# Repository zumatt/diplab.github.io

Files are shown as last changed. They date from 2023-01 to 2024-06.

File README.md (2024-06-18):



# DiPLab - Digital Petri Laboratory


DiPLab is a project that is part of [MAKEAWARE!](https://spearhead-amr.github.io/makeaware/) , which aims to raise awareness about the issue of [Antibiotic Resistance](https://www.who.int/news-room/fact-sheets/detail/antibiotic-resistance).

By digitizing the [antibiogram test](https://en.wikipedia.org/wiki/Antibiotic_sensitivity_testing), it is now possible to experience it outside of microbiology laboratories. This workshop provides an exciting opportunity for participants to deepen their understanding of antibiotics and antibiotic resistance. Additionally, participants will have the chance to engage in practical activities and learn about the test in a hands-on setting. This comprehensive workshop aims to help participants gain a deeper appreciation for the significance of antibiotics and their impact on daily life. By attending this workshop, participants will be able to broaden their knowledge of antibiotics and antibiotic resistance and explore the role of these life-saving drugs in modern medicine.

This repository contains the stable version of the DiPLab. In order to create your own digital petri you can download the source code and the 3D files from the releases.

The project has started as a personal thesis project developed during the [SUPSI Master of Arts in Interaction Design](https://maind.supsi.ch).



## Bugs & Issues

If you want to report an issue, you can submit it to the [issue tracker](https://github.com/zumatt/diplab/issues) of this repository.

## Repository info

Inside the main branch you will find the stable version of DiPLab. However, if you want to create your own digital petri is suggested to download the [latest release](https://github.com/zumatt/diplab/releases) and follow the tutorial that you can find here below.
The main branch is divided into hardware and software. In the hardware you will find the 3D files used to create the external case of the DiPLab. In the software folder you will find anything connected to the digital development of the digital petri, here inside you can find the Arduino source code and the application source code.

## Hardware

The project is based on the board [Soldered Inkplate 6PLUS](https://soldered.com/product/soldered-inkplate-6plus-with-enclosure-e-paper-display-with-touchscreen-usb-only/) with an additional custom board to add the accellerometer sensor into the project.
If you want to replicate the experience, you can buy the mother board [here](https://soldered.com/product/soldered-inkplate-6plus-with-enclosure-e-paper-display-with-touchscreen-usb-only/) and print the custom PCB with the files contained into the folder hardware>accellerometer PCB

## Installation tutorial

In order to create your own digital petri you need to be aware on how to use a 3D Printer and have basic knowledge of Arduino and coding.
The tutorial will be developed soon...

## License

The code contained in this repository and the executable distributions are licensed under the terms of the [MIT License](https://mit-license.org/). The project is released under the terms of the [CC BY SA](https://creativecommons.org/licenses/by-sa/2.0/) license.

[][cc-by-sa]

[cc-by-sa]: http://creativecommons.org/licenses/by-sa/4.0/
[cc-by-sa-image]: https://i.creativecommons.org/l/by-sa/4.0/88x31.png
[cc-by-sa-shield]: https://img.shields.io/badge/License-CC%20BY%20SA%204.0-lightgrey.svg

## Acknowledgments




MAKEAWARE! is part of [Spearhead Project](https://spearhead-project.ch/). [Innosuisse Flagship 2022-24](https://www.innosuisse.ch/inno/en/home/promotion-of-national-projects/flagship-initiative.html).

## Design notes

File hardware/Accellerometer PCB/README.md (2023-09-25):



# DiPLab - Digital Petri Laboratory

DiPLab is a project that is part of [MAKEAWARE!](https://spearhead-amr.github.io/makeaware/) , which aims to raise awareness about the issue of [Antibiotic Resistance](https://www.who.int/news-room/fact-sheets/detail/antibiotic-resistance).

## Accellerometer PCB

This part of the repository contains the personalised PCB created in order to add the accellerometer to the [Inkplate 6 PLUS](https://github.com/SolderedElectronics/Soldered-Inkplate-6PLUS-hardware-design).



The board is based on the [LIS3DH accellerometer](https://www.st.com/resource/en/datasheet/lis3dh.pdf) component and the [easyC connector](https://soldered.com/easyC/) from Soldered Electronics.
Is it possible to use the accellerometer for any purpose including other boards using the 4 through-hole pins.
The shield is designed in collaboration with [Marco Lurati](https://github.com/marclura).

## Bugs & Issues

If you want to report an issue, you can submit it to the [issue tracker](https://github.com/zumatt/diplab/issues) of this repository.

## Repository info

Inside the main branch you will find the stable version of DiPLab. However, if you want to create your own digital petri is suggested to download the [latest release](https://github.com/zumatt/diplab/releases) and follow the tutorial that you can find here below.
The main branch is divided into hardware and software. In the hardware you will find the 3D files used to create the external case of the DiPLab. In the software folder you will find anything connected to the digital development of the digital petri, here inside you can find the Arduino source code and the application source code.

## License

The code contained in this repository and the executable distributions are licensed under the terms of the [MIT License](https://mit-license.org/). The project is released under the terms of the [CC BY SA](https://creativecommons.org/licenses/by-sa/2.0/) license.

[][cc-by-sa]

[cc-by-sa]: http://creativecommons.org/licenses/by-sa/4.0/
[cc-by-sa-image]: https://i.creativecommons.org/l/by-sa/4.0/88x31.png
[cc-by-sa-shield]: https://img.shields.io/badge/License-CC%20BY%20SA%204.0-lightgrey.svg

## Acknowledgments




MAKEAWARE! is part of [Spearhead Project](https://spearhead-project.ch/). [Innosuisse Flagship 2022-24](https://www.innosuisse.ch/inno/en/home/promotion-of-national-projects/flagship-initiative.html).

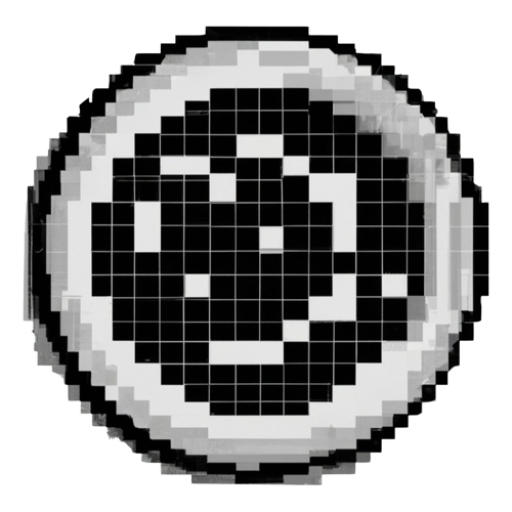
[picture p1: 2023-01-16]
diplab-app/alphaVersion/assets/android-chrome-512x512.png

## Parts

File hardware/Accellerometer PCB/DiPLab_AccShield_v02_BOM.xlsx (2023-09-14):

No. | Quantity | Comment | Designator | Footprint | Value | Manufacturer Part | Manufacturer | Supplier Part | Supplier
1 | 1 | 100nF | C1 | C0402 | 100nF | 0402B104K250NT | FH(风华) | C56392 | LCSC
2 | 1 | 10uF | C2 | C1206 | 10uF | CL31A106KAHNNNE | SAMSUNG(三星) | C9807 | LCSC
3 | 1 | easyC | EASYC1 | CONN-SMD_4P-P1.00_SM04B-SRSS-TB-LF-SN |  | SM04B-SRSS-TB(LF)(SN) | JST | C160404 | LCSC
4 | 1 | LIS3DHTR | U1 | LGA-16_L3.0-W3.0-P0.50-TL |  | LIS3DHTR | ST(意法半导体) | C15134 | LCSC

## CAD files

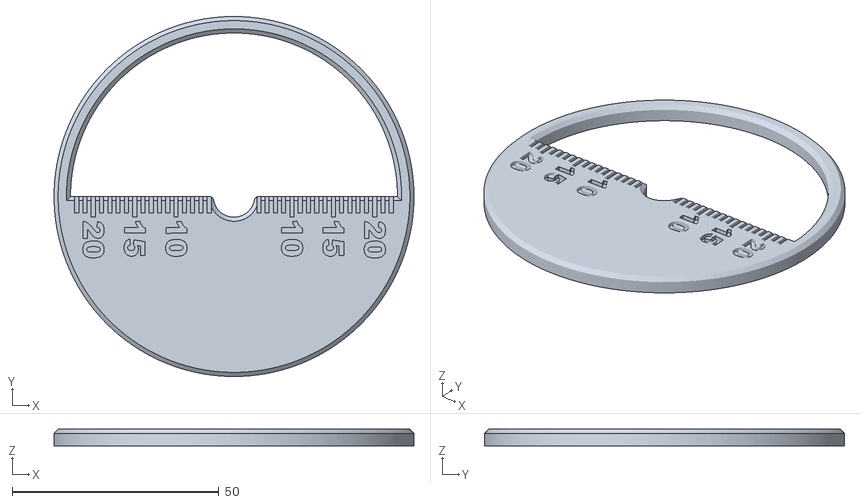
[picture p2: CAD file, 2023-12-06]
hardware/3D Printed case/DiPLab 3D Physical Tool.stl
87.0 x 87.0 x 4.00

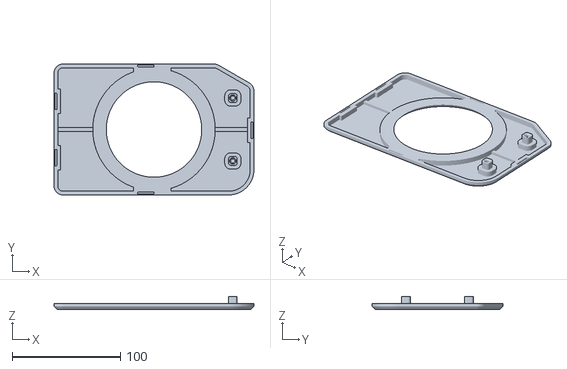
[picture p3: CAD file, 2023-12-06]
hardware/3D Printed case/DiPLab 3D Printed Cover - UpperBlack.stl
184.4 x 120.8 x 12.2

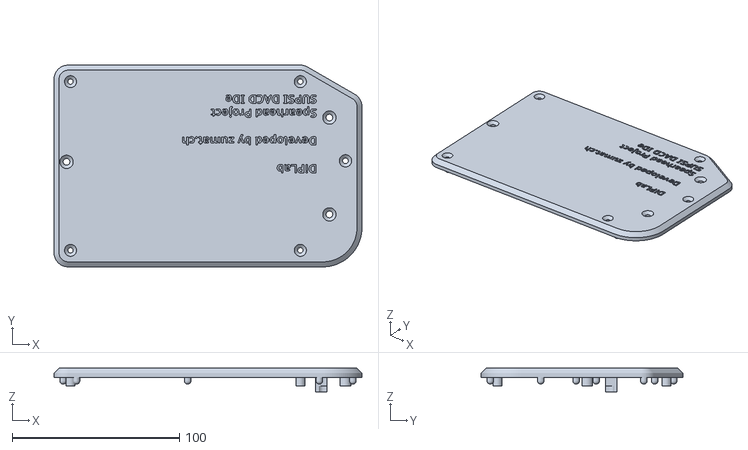
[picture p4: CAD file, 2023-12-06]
hardware/3D Printed case/DiPLab 3D Printed Cover - LowerBlack.stl
184.4 x 120.8 x 14.1

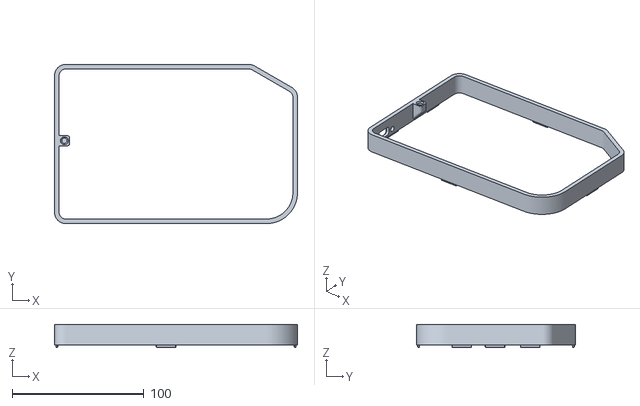
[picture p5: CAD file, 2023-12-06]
hardware/3D Printed case/DiPLab 3D Printed Cover - UpperColoured.stl
184.4 x 120.8 x 17.7

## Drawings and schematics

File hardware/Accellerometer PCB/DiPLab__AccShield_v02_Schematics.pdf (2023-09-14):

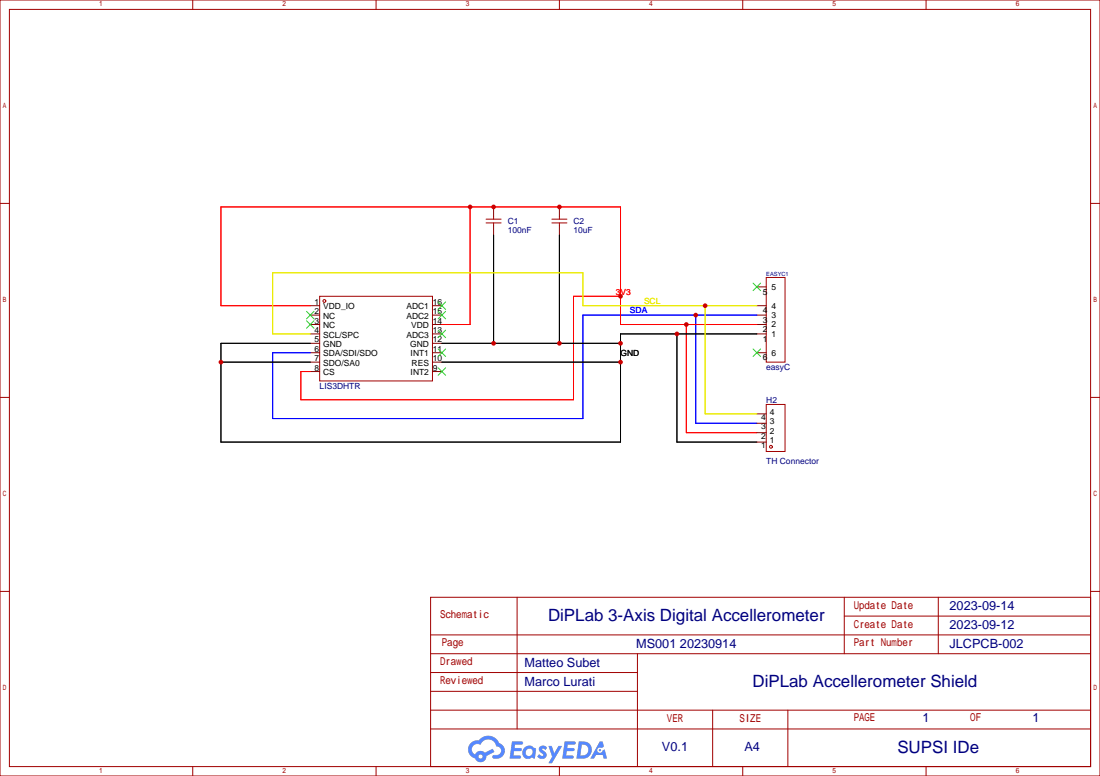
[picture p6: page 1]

2023-09-12 DiPLab 3-Axis Digital Accellerometer

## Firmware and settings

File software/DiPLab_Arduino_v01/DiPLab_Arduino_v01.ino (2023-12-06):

/* MIT License 2023 Matteo Subet <hi@zumat.ch>
   
   Release Version 0.1 - DiPLaB
   Spearhead Research Project - https://spearhead-amr.github.io/makeaware/
   
        Coded by Matteo Subet - Last version of 30 November 2023
   
   SUPSI - University of Applied Sciences and Arts of Southern Switzerland
   DACD - Department of Architecture, Construction and Design
   IDe - Design Institute

   Based on Inkplate 6PLUS (ESP32).
   You can find the complete repository here: https://github.com/zumatt/diplab
*/





/*
    -----------------------------------------------------------
                            BOARD CHECK
    -----------------------------------------------------------
*/
#if !defined(ARDUINO_INKPLATE6PLUS) && !defined(ARDUINO_INKPLATE6PLUSV2)
  #error "Wrong board selection for this example, please select Inkplate 6PLUS in the boards menu."
#endif





/*
    -----------------------------------------------------------
                            LIBRARIES
    -----------------------------------------------------------
*/
#include "Inkplate.h"
#include <WiFi.h>
#include <AsyncTCP.h>
#include "ESPAsyncWebSrv.h"
#include "SPIFFS.h"
#include "LIS3DHTR.h"
#include <Wire.h>
LIS3DHTR<TwoWire> LIS; //IIC
#define WIRE Wire
#include <WebSocketsServer.h>
#include <ArduinoJson.h>
#include "Fonts/FreeSansBold9pt7b.h"
    //Font setup for FreeSansBold9pt7b
    const GFXfont *textFont = &FreeSansBold9pt7b;





/*
    -----------------------------------------------------------
                            VARIABLES
    -----------------------------------------------------------
*/
//String to save the Access Point SSID and password
    const char* ssid = "GreenDiPLab";
    const char* password = "FightAMR2023";

//String to save the height and width of the display
    int screenWidth = E_INK_WIDTH;                                              //Width of the display from the library
    int screenHeight = E_INK_HEIGHT;                                            //Height of the display from the library

//Variables to store the petri position and dimension
    int petriDiameter = (screenHeight/2)-10;                                           //Diameter of the petri dish
    
    int yCenter = screenHeight/2;                                                      //Center y of petri dish
    int xCenter = screenWidth/2  - 150;                                                //Center x of petri dish
    int xLeftPetri =  (xCenter)-(petriDiameter);                                       //X position of left side of petri dish
    int yTopPetri =  (yCenter)-(petriDiameter);                                        //Y position of top side of petri dish
    int xRightPetri = (xCenter)+(petriDiameter);                                       //X position of right side of petri dish
    int yBottomPetri = (yCenter)+(petriDiameter);                                      //Y position of bottom side of petri dish

//Variables to store information from the web application
    int    webState;                    //State value from the web page
    String webBacteria;                 //Bacteria name from the web page
    String webAb1;                      //Antibiotic 1 name from the web page
    String webAb2;                      //Antibiotic 2 name from the web page
    String webAb3;                      //Antibiotic 3 name from the web page
    String webOperatorName;             //Operator name from the web page
    int    webPatientCode;              //Patient code from the web page
    String webReadingAB;                //Check wich antibiotic is being read (useful for state 5: control center)
    String webReadingBact;              //Hour passed 0h / 8h / 12h / 24h (useful for state 5: control center)
    int    webReadingTime;              //Unknown for now...
    String webControlCenter;            //Control center function selected from the web page

//Controller for screen ready to spread bacteria
    bool readyToSpread;

//Variables to store information about bacteria spreading
    int    bacteriaLinesStep = petriDiameter/10;                                //Step of each line of bacteria
    float  bacteriaDotsX[500];                                                  //Array that contains all the X values of the dots created for the bacteria growth
    float  bacteriaDotsY[500];                                                  //Array that contains all the Y values of the dots created for the bacteria growth

    float  bacteriaZone = bacteriaLinesStep/2;                                  //General dimension of the rectangle created to spread bacteria
    int    bacteriaSpreadY[21] = {0,0,0,0,0,0,0,0,0,0,0,0,0,0,0,0,0,0,0,0,0};   //Array of Y axis for checking if a line was drawn
    int    lenBactSpreadY = *(&bacteriaSpreadY + 1) - bacteriaSpreadY;          //Array of Y axis length
    bool   completeBactSpreadY;                                                 //Bool to check if the bacteria spread is completed on X axis
    int    bacteriaSpreadX[20] = {0,0,0,0,0,0,0,0,0,0,0,0,0,0,0,0,0,0,0,0};     //Array of X axis for checking if a line was drawn
    int    lenBactSpreadX = *(&bacteriaSpreadX + 1) - bacteriaSpreadX;          //Array of X axis length
    bool   completeBactSpreadX;                                                 //Bool to check if the bacteria spread is completed on Y axis
    bool   arrayCompletedSpreading;                                             //Bool to check if the bacteria spread is completed on both axis
    double accelValueX;                                                         //Variable to store accellerometer data on X axis
    double accelValueY;                                                         //Variable to store accellerometer data on Y axis

//Variables to store information about antibiotics position and dimension
    int    abDiameter = 35;                                                     //Dimension of the AB tablet
    int    tresholdAntibioticPosition = 150;                                    //Threshold between two anbiotics pills
    double abMmToPxMultiplier = 0.36;                                           //Multiplier from pixels to mm for ab resistance

    int    ab1XPos, ab1YPos;                                                    //X and Y position of AB 1
    int    ab2XPos, ab2YPos;                                                    //X and Y position of AB 2
    int    ab3XPos, ab3YPos;                                                    //X and Y position of AB 3
    double ab1Resistance;                                                       //Resistance of AB 1 expressed in mm as reported in the antibiotic sheet
    double ab2Resistance;                                                       //Resistance of AB 2 expressed in mm as reported in the antibiotic sheet
    double ab3Resistance;                                                       //Resistance of AB 3 expressed in mm as reported in the antibiotic sheet
    int    antibioticsCreated = 0;                                              //Numbers of antibiotic placed
    int    oldCoordX1 = 0;                                                      //Variable to store the old X position of AB 1
    int    oldCoordY1 = 0;                                                      //Variable to store the old Y position of AB 1
    int    oldCoordX2 = 0;                                                      //Variable to store the old X position of AB 2
    int    oldCoordY2 = 0;                                                      //Variable to store the old Y position of AB 2
    int    oldCoordX3 = 0;                                                      //Variable to store the old X position of AB 3
    int    oldCoordY3 = 0;                                                      //Variable to store the old Y position of AB 3
    int    ab1WebX, ab1WebY;                                                    //Position of first antibiotic on the web page
    int    ab2WebX, ab2WebY;                                                    //Position of second antibiotic on the web page
    int    ab3WebX, ab3WebY;                                                    //Position of third antibiotic on the web page
    int    ab1ResistanceWeb, ab2ResistanceWeb, ab3ResistanceWeb;                //Store resistance value for each AB to display it on the web page

//Variables to store information about the Access Point
    IPAddress serverIP;                                                         //IP address of the server
    int interval = 1000;                                                        //Interval between each check of the IP address
    unsigned long previousMillis = 0;                                           //Variable to store the previous time





/*
    -----------------------------------------------------------
                    FUNCTIONS TO SETUP THE BOARD
    -----------------------------------------------------------
*/
//Create AsyncWebServer object on port 80
    AsyncWebServer server(80);

//Create webSocket on port 81
    WebSocketsServer webSocket = WebSocketsServer(81);

// Create an object on Inkplate library and also set library into 1 Bit mode (BW)
    Inkplate display(INKPLATE_1BIT);





/*
    -----------------------------------------------------------
                    SETUP WIFI AND SDCARD FUNCTIONS
    -----------------------------------------------------------
*/

//Function to check if the SD card is working properly
void initSPIFFS(){
    //Condition to check if the SD card is working properly
    if(!SPIFFS.begin(true)){
        Serial.println("An Error has occurred while mounting SPIFFS");
        return;
    }
}

//Function to start the Wifi connection in Access Point mode
void initWiFi() {
    WiFi.begin();                       //Start the WiFi connection
    WiFi.mode(WIFI_AP);                 //WIFI_AP is equal of Access Point mode
    WiFi.softAP(ssid, password);        //AccessPoint ssid and pss
    Serial.print("IP Address: ");
        serverIP = WiFi.softAPIP();     //Get the IP address of the server
    Serial.println(serverIP);           //Here we print the IP Address of the AccessPoint
}

/*
    -----------------------------------------------------------
                          SETUP FUNCTION
    -----------------------------------------------------------
*/

void setup() {
    //Start the serial communication
        Serial.begin(115200);

    //Begin and clear display
        display.begin();
        display.clearDisplay();
        display.display();
        display.setCursor(xLeftPetri+90, yTopPetri+200);
        display.setTextSize(2);
        display.println("Setting up the system...");
        display.display();

    //Setup accellerometer
        LIS.begin(WIRE,0x18); //IIC init
        delay(100);
        LIS.setFullScaleRange(LIS3DHTR_RANGE_4G);
        LIS.setOutputDataRate(LIS3DHTR_DATARATE_50HZ);
        if (!LIS){
          Serial.println("ERROR! - LIS3DHTR didn't connect.");
        } else {
          Serial.println("LIS3DHTR connect completed!");
        }

    //Display settings
        display.setFont(textFont);
        display.setTextSize(2);
        display.setTextColor(BLACK, WHITE);
        display.setTextWrap(true);

    //Start the WiFi connection
        Serial.println("WiFi init:");
        initWiFi();
        Serial.println("WiFi init END");

    //Start the SPIFFS
        Serial.println("SPIFFS init START");
        initSPIFFS();
        Serial.println("SPIFFS init END");

    //Setup of the server first webpage and connected files (e.g. css, favicon, etc.)
        server.on("/", HTTP_GET, [](AsyncWebServerRequest *request){
            request->send(SPIFFS, "/index.html", "text/html");
        });
        server.serveStatic("/", SPIFFS, "/");

    //Start the server & the webSocket
        server.begin();
        webSocket.begin();

    //When receiving a message from the webSocket, call the webSocketEvent function
        webSocket.onEvent(webSocketEvent);

    //Start the display and check if it works properly
        if (display.tsInit(true)){
            Serial.println("Touchscreen init ok");}
        else {
            Serial.println("Touchscreen init fail");
            //while (true);
            }

    //Start with the experience
        state0();

    //Create all the dots for the display of bacteria growing
        for(int i=0; i<500; i++){
            bacteriaDotsX[i] = random(xLeftPetri, xRightPetri);
            bacteriaDotsY[i] = random(yTopPetri, yBottomPetri);
        }
}




/*
    -----------------------------------------------------------
                          LOOP FUNCTION
    -----------------------------------------------------------
*/

void loop() {
    //Check if there is a message from the webSocket
        webSocket.loop();
    
    //Check if we are in the state for bacteria spreading
    if(webState == 2){
        //Call drawing function for bacteria
            if(webState == 2 && readyToSpread == 1){
            //Update variables for accellerometer
            accelValueX = -LIS.getAccelerationX(); //Get accellerometer X data
            accelValueY = -LIS.getAccelerationY(); //Get accellerometer Y data

            drawingLoop();

                if (arrayCompletedSpreading == true){
                    String jsonString = "";
                    StaticJsonDocument<200> doc;                      // create a JSON container
                    JsonObject object = doc.to<JsonObject>();         // create a JSON Object
                    object["spreadingBacteria"] = 1;                  // write data into the JSON object -> I used "rand1" and "rand2" here, but you can use anything else
                    serializeJson(doc, jsonString);                   // convert JSON object to string
                    Serial.println(jsonString);                       // print JSON string to console for debug purposes (you can comment this out)
                    webSocket.broadcastTXT(jsonString);               // send JSON string to clients
                    } else {
                        checkLoopSpreading();
                    }
            } //END IF data from accellerometer
    }

    //Call touchscreen functions for antibiotics placing
    if (webState == 4){
            abPlacing();
    }
}




/*
    -----------------------------------------------------------
             RECEIVING A MESSAGE FROM THE WEB PAGE
    -----------------------------------------------------------
*/

void webSocketEvent(byte num, WStype_t type, uint8_t * payload, size_t length) { // event structure

  switch (type) {
    case WStype_TEXT:
      // try to decipher the JSON string received
        StaticJsonDocument<200> doc;                                      // create a JSON container
        DeserializationError error = deserializeJson(doc, payload);       // deserialize the JSON document
        if (error) {
            Serial.print(F("deserializeJson() failed: "));
            Serial.println(error.f_str());                                  // print the error if there is one  
            return;
        }
        else {
            // JSON string was received correctly, so information can be retrieved:
                //Create temporary variables to store the information received from the web page
                String tempOperatorName, tempBacteria, tempAb1, tempAb2, tempAb3, tempControlCenter, tempReadingBact;

            //Store the information received from the web page        
                const int   receivedState         = doc["state"];
                const char* receivedBacteria      = doc["bacteria"];
                const char* receivedAb1           = doc["ab1"];
                const char* receivedAb2           = doc["ab2"];
                const char* receivedAb3           = doc["ab3"];
                const char* receivedOperatorName  = doc["name"];
                const int   receivedPatientCode   = doc["patientcode"];
                const int   receivedReadingAb     = doc["readingAb"];
                const char* receivedReadingBact   = doc["readingBact"];
                const int   receivedReadingTime   = doc["readingTime"];
                const char* receivedControlCenter = doc["controlCenter"];

            //Store the information received from the web page in the temporary variables        
                tempOperatorName    = receivedOperatorName;
                tempBacteria        = receivedBacteria;
                tempAb1             = receivedAb1;
                tempAb2             = receivedAb2;
                tempAb3             = receivedAb3;
                tempControlCenter   = receivedControlCenter;
                tempReadingBact     = receivedReadingBact;

            //Store the information received from the web page in the global variables
                                                            webState            = receivedState;
                if (tempOperatorName.length() != 0){        webOperatorName     = receivedOperatorName; }
                if (tempBacteria.length() != 0){            webBacteria         = receivedBacteria;     }
                if (tempAb1.length() != 0){                 webAb1              = receivedAb1;          }
                if (tempAb2.length() != 0){                 webAb2              = receivedAb2;          }
                if (tempAb3.length() != 0){                 webAb3              = receivedAb3;          }
                if (receivedPatientCode != 0){              webPatientCode      = receivedPatientCode;  }
                                                            webReadingAB        = receivedReadingAb;
                if (tempReadingBact.length() != 0){         webReadingBact      = receivedReadingBact;  }
                                                            webReadingTime      = receivedReadingTime;
                if (tempControlCenter.length() != 0){       webControlCenter    = receivedControlCenter;}
            
            //Call function related to the state received from the web page
                expState(receivedState);

            //Print in console the information saved on the Petri from the web page
                Serial.println("----------------------------------");
                Serial.println("");
                Serial.println("Info received from webPage:");
                Serial.println("");
                Serial.print("  - State: ");
                    Serial.println(webState);
                Serial.print("  - Name: ");
                    Serial.println(webOperatorName);
                Serial.print("  - Classcode: ");
                    Serial.println(webPatientCode);
                Serial.print("  - Bacteria: ");
                    Serial.println(webBacteria);
                Serial.print("  - Antibiotic 1 : ");
                    Serial.println(webAb1);
                Serial.print("  - Antibiotic 2 : ");
                    Serial.println(webAb2);
                Serial.print("  - Antibiotic 3 : ");
                    Serial.println(webAb3);
                Serial.print("  - Control center : ");
                    Serial.println(webControlCenter);
                Serial.print("    - Reading AB : ");
                    Serial.println(webReadingAB);
                Serial.print("    - Reading Bact : ");
                    Serial.println(webReadingBact);
                Serial.print("    - Reading time : ");
                    Serial.println(webReadingTime);
                Serial.println("");
                Serial.println("----------------------------------");
        }
        break;
    }
}




/*
    -----------------------------------------------------------
                      EXPERIENCE CONTROLLER
    -----------------------------------------------------------
*/
void expState(int stateVariable){
    //Call function related to the state received from the web page
        if(stateVariable == 0){
            state0();                       //This is the state where the user start the journey; The trigger to move on is the insert of patient code into the phone;
        } else if(stateVariable == 1){
            state1();                       //This is the state where the user connected correctly showing the patient code and the trigger is the bacteria confirmation;
        } else if(stateVariable == 2){
            state2();                       //This is the state where the user need to spread the bacteria; Trigger is the screen entirely covered with bacteria;
        } else if(stateVariable == 3){
            state3();                       //This is the state where the user need to select the antibiotics; Trigger is the third antibiotic selected;
        } else if(stateVariable == 4){
            state4();                       //This is the state where the user insert the three antibiotics with touchscreen. Trigger is the confirmation or reset position;
        } else if(stateVariable == 5){
            state5();                       //This is the state where the user is in control center;
        } else if(stateVariable == 6){
            state6();                       //This is the state where the user finish the experience, the device is showing the last petri dish. Trigger is on the phone to continue the experience (state 2) or end it.
        } else {
            //Return an error message
                Serial.println("Error: state not found");
        }
}




/*
    -----------------------------------------------------------
                          STATE FUNCTIONS
    -----------------------------------------------------------
*/
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

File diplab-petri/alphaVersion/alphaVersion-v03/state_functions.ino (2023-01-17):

void state0() {
  //Display all the informations for the WiFi connection
  display.clearDisplay();
  display.drawCircle(dispW/2, dispH/2, petriD, BLACK);
  display.setCursor(xC+100, yC+250);
  display.println("Connect to ");
  display.setCursor(xC+100, yC+300);
  display.print(ssid);
  display.println(" WiFi with pass: ");
  display.setCursor(xC+100, yC+350);
  display.println(password);
  display.setCursor(xC+100, yC+400);
  display.print("Open web browser and write");
  display.setCursor(xC+100, yC+450);
  display.print("http://");
  display.print(serverIP);
  display.println('/');
  display.display();
}

void state1() {
  //Confirm the connection and start an introduction to the exp
  display.clearDisplay();
  display.drawCircle(dispW/2, dispH/2, petriD, BLACK);
  display.setCursor(xC+100, yC+300);
  display.println("Your device is connected!");
  display.setCursor(xC+100, yC+350);
  display.println("You can start the experience!");
  display.display();
}

void state6(){
  //Reset AB position for later
  ab1_x = 0;
  ab1_y = 0;
  ab2_x = 0;
  ab2_y = 0;
  ab3_x = 0;
  ab3_y = 0;

  //Reset resistance value for later
  ab1_resistance = 0;
  ab2_resistance = 0;
  ab3_resistance = 0;
  updateResistanceValue();

  //Reset value of inputMessage10 & inputMessage8
  inputMessage8 = "";
  inputMessage10 = "";

  //Start experience: enter Name and class code
  display.clearDisplay();
  display.drawCircle(dispW/2, dispH/2, petriD, BLACK);
  display.setCursor(xC+100, yC+250);
  display.println("Your name:");
  display.setCursor(xC+100, yC+300);
  Serial.print("Name from the web : ");
  Serial.println(inputMessage6);
  display.println(inputMessage6);
  display.setCursor(xC+100, yC+400);
  display.print("Your class code:");
  display.setCursor(xC+100, yC+450);
  display.print("#");
  Serial.print("Class code from the web : ");
  Serial.println(inputMessage7);
  display.println(inputMessage7);
  display.display();
}

void state7(){
  //Bacteria selection
  display.clearDisplay();
  display.drawCircle(dispW/2, dispH/2, petriD, BLACK);
  display.setCursor(xC+100, yC+300);
  display.println(inputMessage2);
  display.setCursor(xC+100, yC+350);
  display.println("is correctly uploaded");
  display.setCursor(xC+100, yC+400);
  display.print("in your DiPLab Petri!");
  display.display();
}

void state8(){
  //Bacteria spreading (everything is in the loop)
  accX = 0;
  accY = 0;
  display.clearDisplay();
  display.drawCircle(dispW/2, dispH/2, petriD, BLACK);
  display.display();
  readyToSpread = 1;
  Serial.println("State 8 activated!");
}

void state9(){
  //Reset controller
  readyToSpread = 0;

  //Antibiotic selection
  if (arrAb[0]+arrAb[1]+arrAb[2] == 3){
    //All antibiotics are displayed
    display.clearDisplay();
    display.drawCircle(dispW/2, dispH/2, petriD, BLACK);
    display.setCursor(xC+100, yC+250);
    display.print("AB 1: ");
    display.println(inputMessage3);
    display.setCursor(xC+100, yC+300);
    display.print("AB 2: ");
    display.println(inputMessage4);
    display.setCursor(xC+100, yC+350);
    display.print("AB 3: ");
    display.println(inputMessage5);
    display.setCursor(xC+100, yC+400);
    display.print("are correctly uploaded");
    display.setCursor(xC+100, yC+450);
    display.println("in your DiPLab Petri!");
    display.display();
  } else if(arrAb[0]+arrAb[1]+arrAb[2] == 2){
      display.clearDisplay();
      display.drawCircle(dispW/2, dispH/2, petriD, BLACK);
      display.setCursor(xC+100, yC+350);
      display.println("You need to select 1 more AB");
      display.partialUpdate();
  } else if (arrAb[0]+arrAb[1]+arrAb[2] == 1){
      display.clearDisplay();
      display.drawCircle(dispW/2, dispH/2, petriD, BLACK);
      display.setCursor(xC+100, yC+350);
      display.println("You need to select 2 more ABs");
      display.partialUpdate();
  } else if (arrAb[0]+arrAb[1]+arrAb[2] == 0){
      display.clearDisplay();
      display.drawCircle(dispW/2, dispH/2, petriD, BLACK);
      display.setCursor(xC+100, yC+350);
      display.println("You need to select 3 ABs");
      display.partialUpdate();
  }
}

void state10(){
  //Insert of Antibiotic (Shake device!)
  accX = 0;
  accY = 0;
  display.clearDisplay();
  display.drawCircle(dispW/2, dispH/2, petriD, BLACK);
  baseLayer();
  display.display();
  Serial.println("State 10 activated!");
}

void state11(){
  //Control center (History/Microscope mode)
  if(inputMessage9 == "1"){
    //The next three lines are only for test!
    //To start test pass the query <ESP_IP>/string?test=1
    ab1_resistance = 2;
    ab2_resistance = 4;
    ab3_resistance = 8;
    updateResistanceValue();
  }
  if(inputMessage10 == "history"){
    Serial.println("We are in history mode!");
    historyMode();
  }else if(inputMessage10 == "microscope"){
    Serial.println("We are in microscope mode!");
    microscopeMode();
  } else{Serial.println("Error in state11");}
}

void state12(){
  //Save the experience
  baseLayer();

      display.fillCircle(ab1_x, ab1_y, abDiameter*ab1_resistance, 0);
      display.fillCircle(ab2_x, ab2_y,  abDiameter*ab2_resistance, 0);
      display.fillCircle(ab3_x, ab3_y,  abDiameter*ab3_resistance, 0);
    display.fillCircle(ab1_x, ab1_y, abDiameter, 1);
    display.fillCircle(ab2_x, ab2_y, abDiameter, 1);
    display.fillCircle(ab3_x, ab3_y, abDiameter, 1);
    display.display();
}

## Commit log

2022-12-30 controlCenter completed
    First rough prototype is done
2023-01-10 esp32 code
2023-01-11 Inkplate library modified - Deleted support SDFat Library & Images display
    Due to an error with the ESPAsyncWebServer.h and in particular with the SD card reader system, it was necessary to delete the support of the SDFat library from the Inkplate library and also the Image.h library that used a lot of SDFat library informations
    [placeAntibiotics.ino]
2023-01-12 New button code
2023-01-13 alphaVersion - hardware working
    The hardware is ok. Is missing the functionality to generate the resistance. Actually is done thanks to a test functionality /string?test=1.
    The next phase will be the development of the webPages.
    [placeAntibiotics.ino, state_functions.ino]
2023-01-14 skip button state1
2023-01-16 fix alpha version 02
    [placeAntibiotics.ino]
2023-01-17 fix for alphaVersion 03
    [placeAntibiotics.ino, state_functions.ino]
2023-01-17 button state12
2023-01-25 Product repo
    [DiPLab-BottomSide.3mf, DiPLab-BottomSide.stl, DiPLab-TopSide.3mf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]
2023-01-30 Changes 3d files
    [Complete product.stl, DiPLab-TopSide.3mf, DiPLab-TopSide.stl]
2023-02-20 betaVersion 01
    [Bottom-DiPLab.3mf, Bottom.stl, Top.stl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]
2023-08-21 Lock zoom at 4x – just for test
2023-08-21 Touchscreen for inserting ABs
    Completed the example to put antibiotics inside the digital petri using the touchscreen. IMPORTANT NOTE: to use is not possible to connect the two buttons. It will be needed to swap the buttons connections to another GPIO.
2023-08-22 Working on beta version 0.2.0
    Integrated history mode, reading mode with dots instead of resistance growing. Integrated touchscreen and small changes on the visual app part to follow the flow correctly.
2023-08-23 Beta Version 02.0 Stable
    Fixed few errors, the beta is now stable with touchscreen - changed also the physical button into touchscreen because the physical ones are not working
2023-08-25 Updates resistance values
2023-09-11 Clean Main
    The development version is moved into the development branch
    [Bottom-DiPLab.3mf, Bottom.stl, Complete product.stl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]
2023-09-14 Release of the accellerometer shield
    Files to replice the accellerometer shield for the DiPLab
    [DiPLab_AccShield_v02_BOM.xlsx, DiPLab_AccShield_v02_PickAndPlace.xlsx]
2023-12-06 DiPLab V1 - 3D Files ready to print
    [DiPLab 3D Printed Cover - LowerBlack.stl, DiPLab 3D Printed Cover - UpperBlack.stl, DiPLab 3D Printed Cover - UpperGreen.stl]
2023-12-06 DiPLab V1 - GCodes & Physical Tool file
    Gcodes are done for a Prusa MK3S with PETG filament
    [DiPLab 3D Physical Tool.stl, DiPLab 3D Printed Cover - UpperColoured.stl]
